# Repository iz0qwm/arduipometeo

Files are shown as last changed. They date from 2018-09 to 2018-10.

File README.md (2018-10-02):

# arduipometeo
Stazione meteorologica per meteorologia ipogea

## Introduzione
sul perchè sia importante monitorare alcuni parametri meteorologici anche all'interno delle grotte (ambiente _ipogeo_),
vi rimando a questa pagina del Gruppo Grotte di Gallarate: [Gruppo Grotte Gallarate](http://www.gruppogrottegallarate.it/meteorologia-ipogea/)

Un mio amico, Casadei Federico, grande appassionato di speleogia nonchè membro attivo del CAI, mi ha chiesto se potevo consigliargli qualche sensore per il minimo monitoraggio ambientale di una grotta.
Così è iniziata l'avventura con Arduino per risparmiare il più possibile visto che la stazione sarebbe rimasta abbandonata per un tempo imprecisato, nel sottosuolo.

## Sensori e PCB
Ecco i componenti utilizzati: 
- Arduino UNO
- DHT22 - sensore di temperatura e umidità 
- BMP280 - sensore di pressione (temperatura come parametro secondario)
- Anemometro Inspeed Vortex
- RTC DS3231 - Real Time Clock (temperatura come parametro secondario)
- Micro SD Card module - Modulo per scheda SD
 
## PCB assembled
Purtroppo, essendo il primo lavoro effettuato con [Fritzing](http://fritzing.org/home/) e la prima volta che usavo [AISLER](https://github.com/iz0qwm/arduipometeo-8c5c2d39-25d2-4da6-ba8e-bfbf6c96123a) per farmi stampare il PCB, ho fatto un errore:
fori di Arduino UNO, fatti al contrario :(  
Inoltre, per un problema del disegno del DS3231, i fori di quest'ultimo sul PCB non erano passanti placcati, quindi la saldatura poteva avvenire solo su un lato del PCB.
**N.B.: La versione 1.5 ha questi problemi risolti**

ARDUIPO_01
ARDUIPO_02
ARDUIPO_03
ARDUIPO_04
ARDUIPO_05

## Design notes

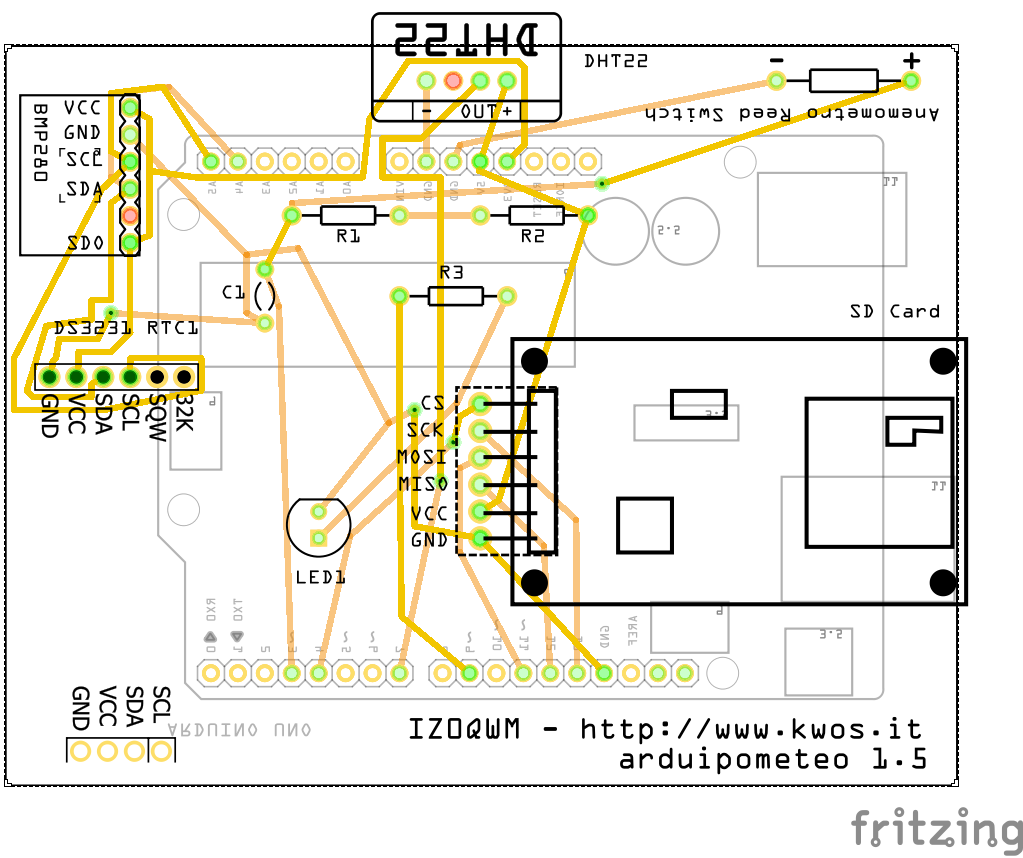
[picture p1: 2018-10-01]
arduipometeo_pcb.png

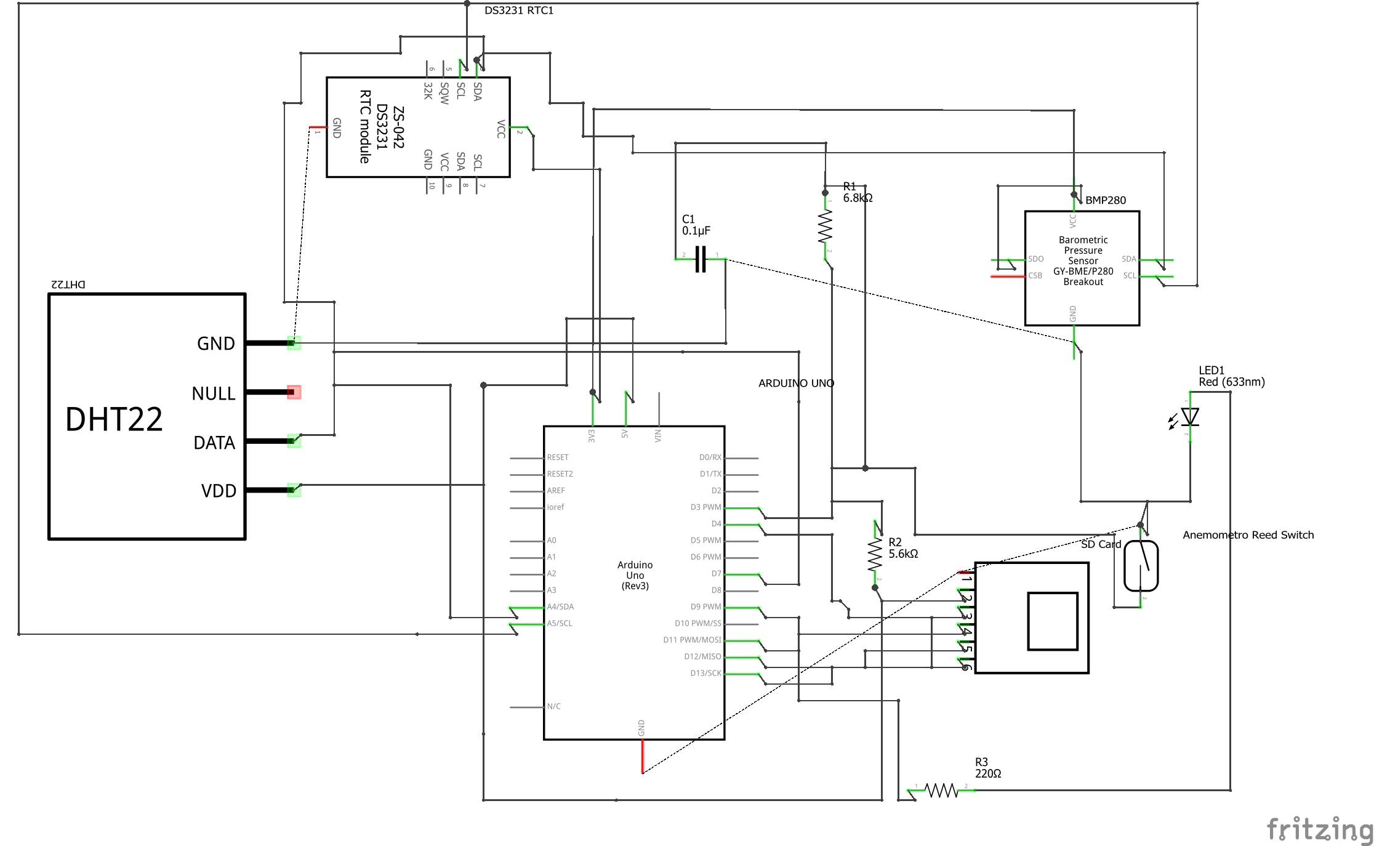
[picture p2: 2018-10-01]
arduipometeo_schem.png

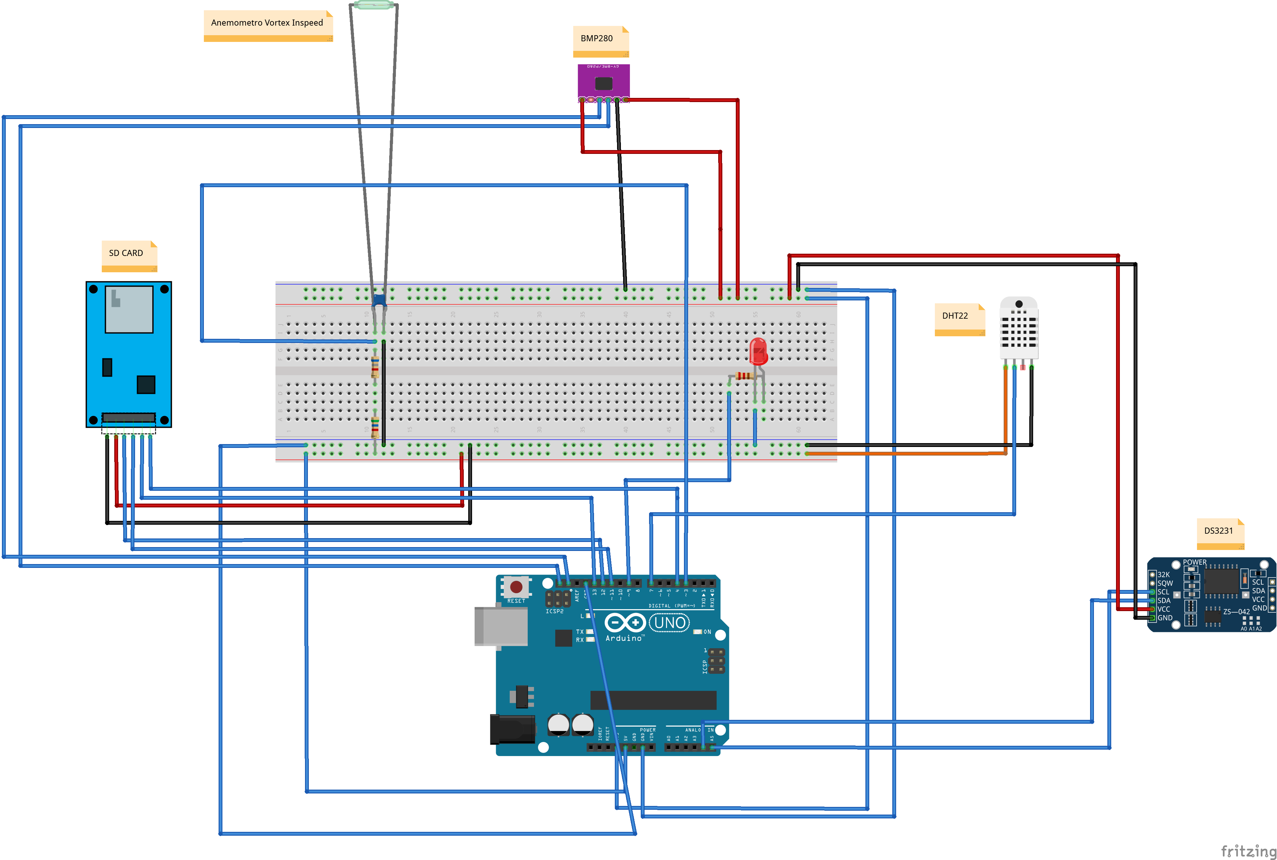
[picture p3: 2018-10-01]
arduipometeo_bb.png

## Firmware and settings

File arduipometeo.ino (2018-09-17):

/* Stazione meteo ipogea
   Raffaello Di Martino IZ0QWM
   http://www.kwos.it */

//Libraries
#include <DHT.h>
#include "RTClib.h"
#include <DS3231.h> // http://www.rinkydinkelectronics.com/library.php?id=73
#include <SPI.h>
#include <SD.h>
#include <Wire.h>
#include <stdio.h>
#include <Adafruit_Sensor.h>
#include <Adafruit_BMP280.h>

//Costanti generiche
int i = 0;
#define PIN_LED 9

//Costanti per termometro
#define DHTPIN 7     // PIN a cui e' collegato il DHT22
#define DHTTYPE DHT22   // DHT 22  (AM2302)
DHT dht(DHTPIN, DHTTYPE); //// Initialize DHT sensor for normal 16mhz Arduino

//Costanti per anemometro
#define PIN_ANEMOMETER 3 // Digital 3
// Tempo di aggiornamento della velocita' del vento
#define MSECS_CALC_WIND_SPEED 5000

//Variabili per anemometro
volatile int numRevsAnemometer = 0; // Incrementato nella funzione countAnemometer()

File logfile;

//Start Modulo RTC 
DS3231  rtca(SDA, SCL); //Solo per leggere
RTC_DS3231 rtc; //RTC DS3231 object per settare l'orario

//Start modulo BMP280
Adafruit_BMP280 bme; // su I2C

void setup()
{
  
  Serial.begin(9600);
  //Led
  pinMode(PIN_LED, OUTPUT);
  //Anemometro
  pinMode(PIN_ANEMOMETER, INPUT);
  digitalWrite(PIN_ANEMOMETER, HIGH);
  attachInterrupt(1, countAnemometer, FALLING);
  // Realtime Clock
  rtca.begin(); // Solo per leggere
  rtc.begin(); // Solo per settare l'orario
  // Sensore pressione
  bme.begin();
  //Serial.print("---------------------------------------------------\n");
  //Serial.print("INIZIALIZZAZIONE\n");
  //Serial.print("---------------------------------------------------\n");
  //Serial.print("Setto l'orario per il log file...\n");
  rtc.adjust(DateTime(F(__DATE__), F(__TIME__))); //Prendiamo l'orario dal PC

  //SD Card
  //Serial.print("Inizializzazione SD Card...\n");

  if (!SD.begin(4)) {// Usiamo il pin 4 dove c'e' il CS per capire se la scheda e' inserita
    //Serial.println("Inizializzazione fallita!\n");
    while (1);
  }
  //Serial.println("Inizializzazione OK.\n");  
  
}

void loop()
{
    digitalWrite(PIN_LED, HIGH); 
    // create a new file
    char filename[] = "LOGGER00.CSV";
    for (uint8_t i = 0; i < 100; i++) {
      filename[6] = i/10 + '0';
      filename[7] = i%10 + '0';
      if (! SD.exists(filename)) {
        //logfile.close();
        logfile = SD.open(filename, FILE_WRITE); 
        // Serial.println("GIORNO,ORA,HUM,TEMPOUT,TEMPINT,WIND,TEMPBARO,PRESS");
        logfile.println("GIORNO,ORA,HUM,TEMPOUT,TEMPINT,WIND,TEMPBARO,PRESS\n");
        logfile.close();
        delay(1000);
      }
      logfile = SD.open(filename, FILE_WRITE);
      delay(500); 
      //Serial.println(logfile.size());
      if (logfile.size() < 2000000) {  // dimensione massima del file di log in bytes
        logfile.close();        
        break;  // esco dal loop!   
      }
      logfile.close();  // Chiudo sempre. ARDUINO non gestisce più di un file aperto
    } 
    logfile = SD.open(filename, FILE_WRITE);
    delay(500);
    String TempHum = calcTempHumidity();
    //Prendo la stringa dalla funzione WindSpeed
    String Wind = calcWindSpeed();
    //Prendo la stringa dalla funzione calcPressure
    String Pressure = calcPressure();
    //Creo la stringa completa
    //String total = DataOra + "," + TempHum + "," + Wind + "," + Pressure;
    logfile.print(rtca.getDateStr());
    logfile.print(",");
    logfile.print(rtca.getTimeStr());
    //logfile.print(DataOra);
    logfile.print(",");
    logfile.print(TempHum);
    logfile.print(",");
    logfile.print(Wind);
    logfile.print(",");
    logfile.print(Pressure);
    logfile.println();
    logfile.close();

    Serial.print(rtca.getDateStr());
    Serial.print(",");
    Serial.print(rtca.getTimeStr());
    Serial.print(",");
    Serial.print(TempHum);
    Serial.print(",");
    Serial.print(Wind);
    Serial.print(",");
    Serial.print(Pressure);
    Serial.print(" -> ");
    Serial.print(filename);
    Serial.println();
    
    digitalWrite(PIN_LED, LOW);
    
    // Azzero le rivoluzioni dell'anemometro
    numRevsAnemometer = 0;
    
    delay(5000); //Delay 5 sec.

}

//=======================================================
// Interrupt handler for anemometer. Richiamato ogni volta che il reedswitch
// si attiva (un giro - revolution).
//=======================================================
void countAnemometer() {
numRevsAnemometer++;
}

String calcTempHumidity() {
    //Variabili per termometro
    float hum;  //Valore umidita' DHT
    float tempOut; //Valore temperatura DHT
    float tempIn;//Valore temperatura DS3231
    dht.begin();
    tempIn = rtca.getTemp();
    //Leggi i dati di temperatura e umidita' e inserisci nelle variabili
    hum = dht.readHumidity();
    tempOut = dht.readTemperature();
    String separatore = ",";
    String hum_temp = hum + separatore + tempOut + separatore + tempIn;
    //Serial.println(hum_temp);
    return hum_temp;
  
}


String calcPressure() {
    float tempBmp;
    tempBmp = bme.readTemperature();
    //Serial.print(bme.readTemperature());
    float pascal, hpa;
    pascal = bme.readPressure();
    //Serial.print(bme.readPressure());
    hpa = pascal * 0.01;
    
    String separatore = ",";
    //Serial.print(meters);
    String temp_press = tempBmp + separatore + hpa;
    //Serial.print(pascal);
    return temp_press;   
} 

//=======================================================
// Calcola la velocita' del vento.
// 1 rev/sec = 2.5 mph
//=======================================================
String calcWindSpeed() {
int y, x, iSpeed;
// This will produce mph * 10
// (didn't calc right when done as one statement)
long speed = 25000;//2.5 mph * 1000
speed *= numRevsAnemometer;
speed /= MSECS_CALC_WIND_SPEED;
iSpeed = speed; // Need this for formatting below

x = iSpeed / 10; // Valore in mph
y = x * 1.60934; // Trasformo in Km/h
String punto = ".";
//Serial.print('.');
x = iSpeed % 10;
String wind = y + punto + x;
return wind;
//Serial.println(wind);
numRevsAnemometer = 0; // Resetta il contatore
}

   

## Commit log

2018-09-08 PCB view
2018-09-08 Fritzing file
    [arduipometeo.fzz]
2018-09-10 Aggiunto LED su pin 9
    Attenzione al PCB
2018-09-11 Sistemato problema di apertura file
    [arduipometeo.ino]
2018-09-11 Aggiunto led di scrittura file
    Il led è tratteggiato sulla PCB perchè deve essere saldato volante.
    [arduipometeo.fzz]
2018-09-12 Aggiunte scritte su PCB
    [arduipometeo.fzz]
2018-10-01 New version 1.5
    [arduipometeo_1.5.fzz]
